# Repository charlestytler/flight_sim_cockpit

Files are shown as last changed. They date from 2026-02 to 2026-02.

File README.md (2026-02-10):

# Flight Sim Cockpit

Repository for Hardware and Embedded Software for flight simulation cockpit and avionics panels that provide input/output for Flight Simulators (DCS).

The cockpit is modeled on a blend of F/A-18C, A-10C, F-15E, and F-16C cockpits.

## Software 

The software directory contains embedded software that runs on Arduino and Raspberry Pi microcontrollers.
These connect to a PC via USB and emulate USB HID joystick devices and also communicate with DCS-BIOS software.

To-do: Develop a Windows PC middleware to connect USB Serial -> Middleware -> DCS-BIOS and avoid flashing DCS module-specific code to the microcontrollers.

## Hardware

(Partially) assembled cockpit.  

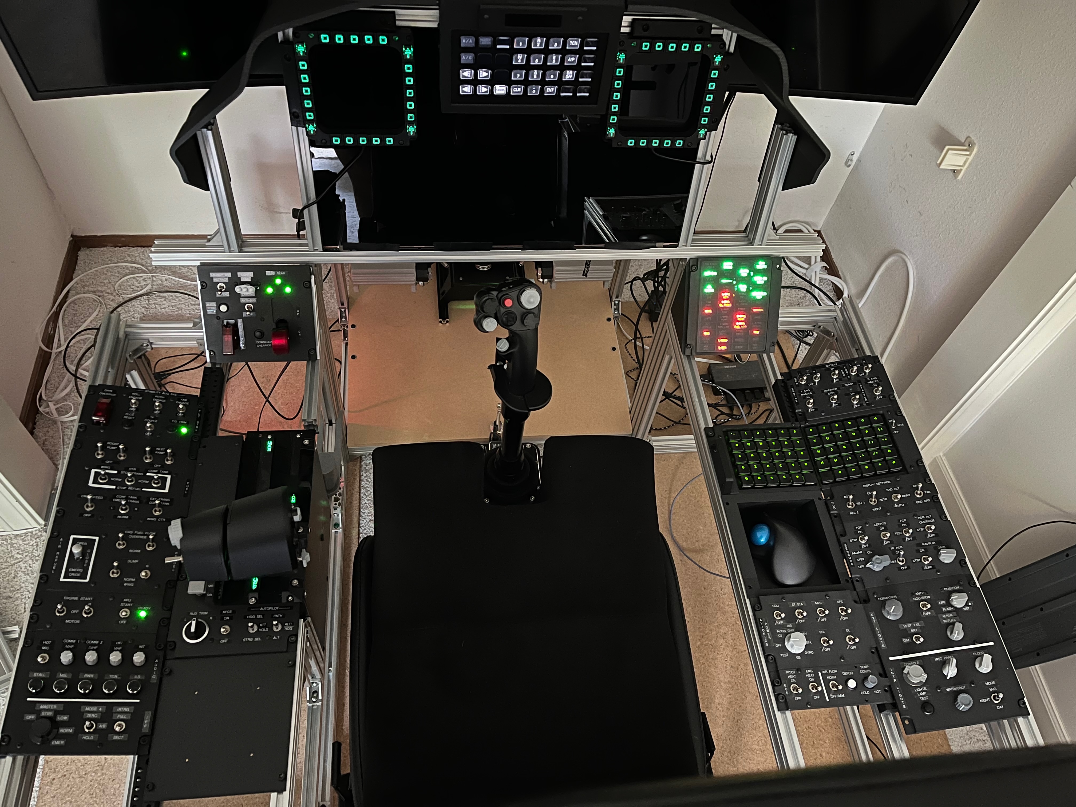
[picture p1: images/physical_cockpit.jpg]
Physical Cockpit


### CAD Models

#### [Link to Fusion 360 Web Viewer of CAD Model](https://a360.co/4bIpcXp)
- Frame is built out of 2040 and 2020 aluminum extrusion according to the CAD model.
- Chair frame uses same extrusion and also 3D Printed TPU surrounding bearings for sliding in/out.
- For complex angles (such as left/right console outer rails and corners), extrusion connectors are 3D printed.
- The panels themselves are a mix of 3D prints or acrylic machined with a CNC router.
- Temporary labels are added with a Brother label maker and 6mm white on black tape.
- Permanent labels are made by painting white acrylic panels matte black and laser engraving the text and symbols.
- Glare shield is designed in multiple parts to enable printing on a 256x256 3D printer bed.
  
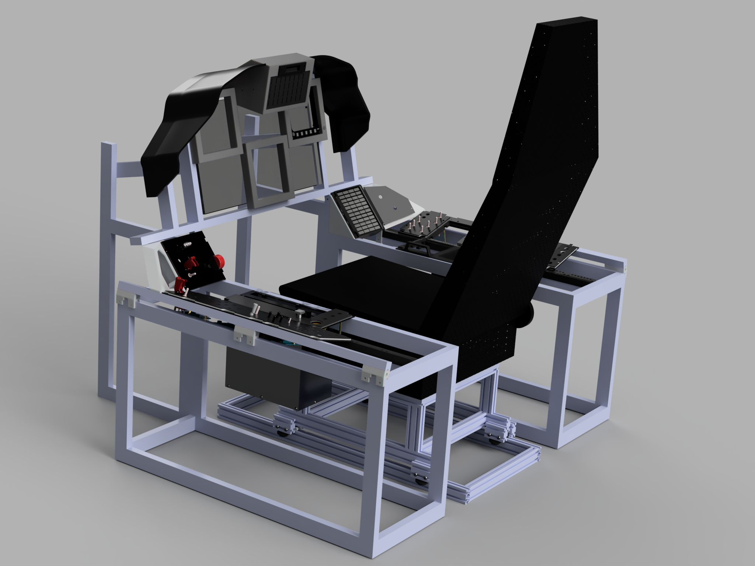
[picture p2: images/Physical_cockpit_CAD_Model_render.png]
CAD Model Rendering of Physical Cockpit


### PCBs

Current version of PCBs using:
 - Arduino Micro Pro (Atmel ATmega32U4)
    - Central processor for all I/O
    - Emulates a USB HID Joystick device
    - Communicates over Serial to PC middleware
    - Likely will upgrade to RP2040 Pico boards in next revision
 - PCF8575 I2C Expanders
    - Provides 16 digital I/O pins per board
    - Inputs used for Switches, Outputs used for indication LEDs
 - CD74HC4067 Multiplexers
    - Provides 16 to 1 analog input multiplexing
    - Used for reading analog potentiometers
 - RP2040 Raspberry Pi Pico (external of PCB)
    - Used for reading rotary encoders
    - Uses PIO to provide parallel handling of encoder interrupts
 - Screw Terminal breakouts

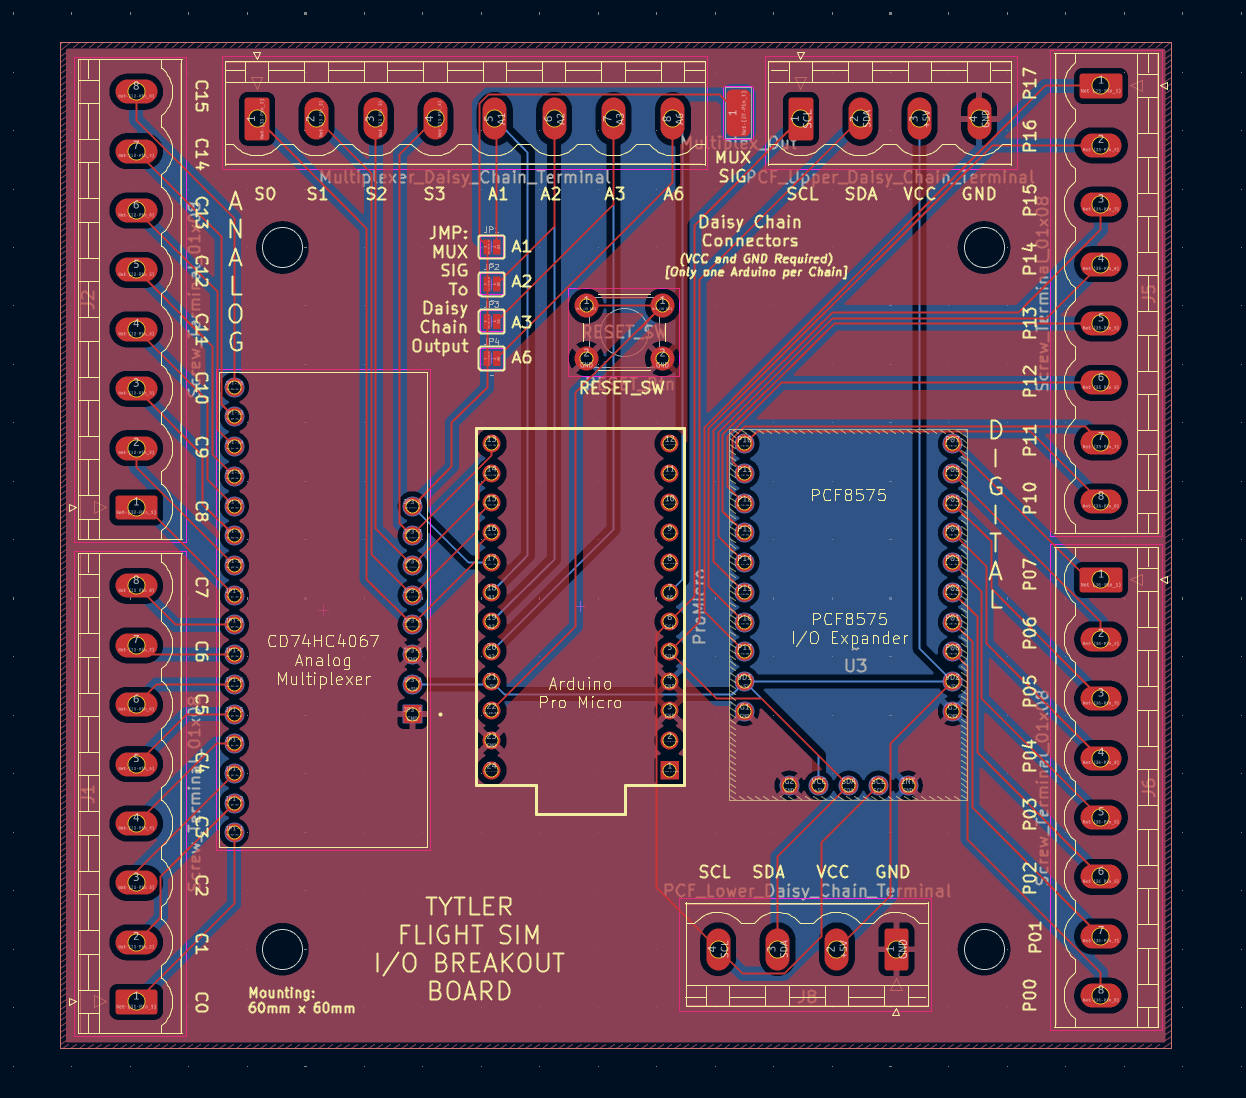
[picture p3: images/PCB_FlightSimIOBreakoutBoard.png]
PCB Layout

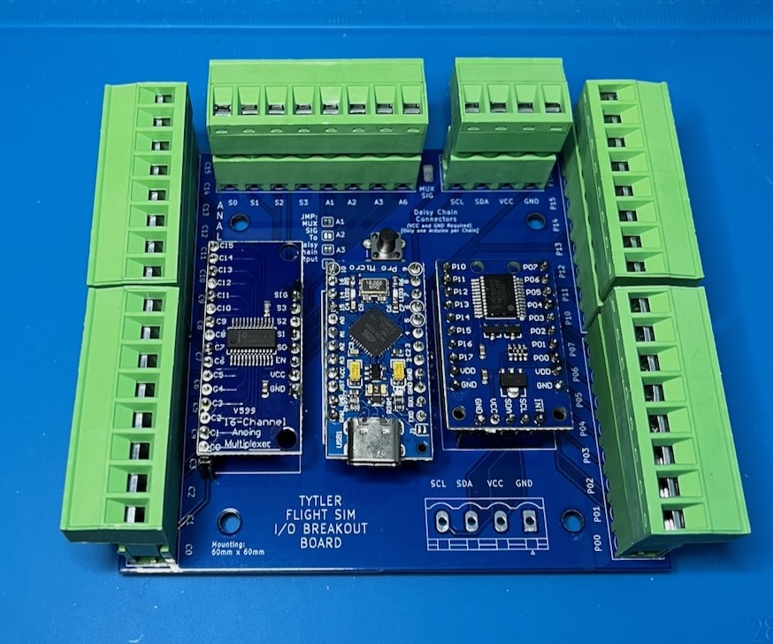
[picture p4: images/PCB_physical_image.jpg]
PCB with Soldered Components


### Cockpit Layout

The layout of avionics panels is a combination of functions from multiple aircraft, so some panels are replicas of specific aircraft, where others are a mix of multiple or have labels renamed to more generic functionality.

#### [Link to Cockpit Layout comparison to Real Aircraft layouts [Figma document]](https://www.figma.com/design/4pN5J7COTx5o1YJxnx6NWO/Layout-Diagram?node-id=0-1&t=OCtYUoI0DKsqzIj2-1)
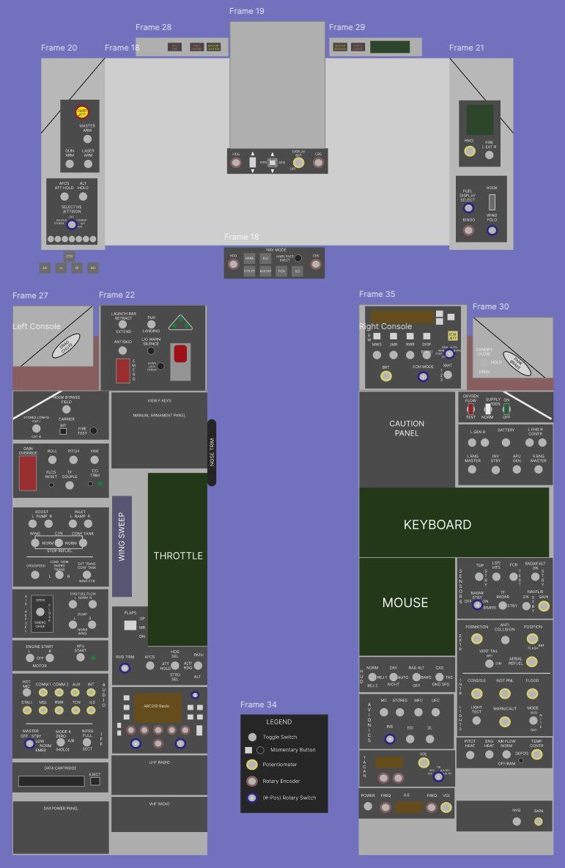
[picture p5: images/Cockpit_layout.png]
Cockpit Layout


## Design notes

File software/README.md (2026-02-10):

# Software

## Build Instructions

To compile: `make <board_name>`

To upload: `make upload <board_name>-upload PORT=COM<#>`
> *Note: if PORT is not specified a warning will print available ports*

To monitor Serial output: `make monitor PORT=COM<#>`

## Prerequisites
Must have arduino-cli installed: https://arduino.github.io/arduino-cli/latest/

Makefiles have been set up to use arduino-cli installed in Windows (arduino-cli.exe) but can be executed from WSL linux bash.

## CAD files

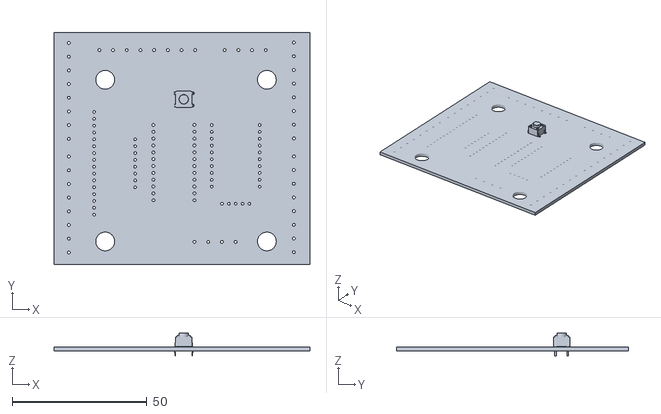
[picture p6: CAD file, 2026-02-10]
hardware/pcb/FlightSimIOBoard/FlightSimIOBoard.stl
95.0 x 86.0 x 8.50

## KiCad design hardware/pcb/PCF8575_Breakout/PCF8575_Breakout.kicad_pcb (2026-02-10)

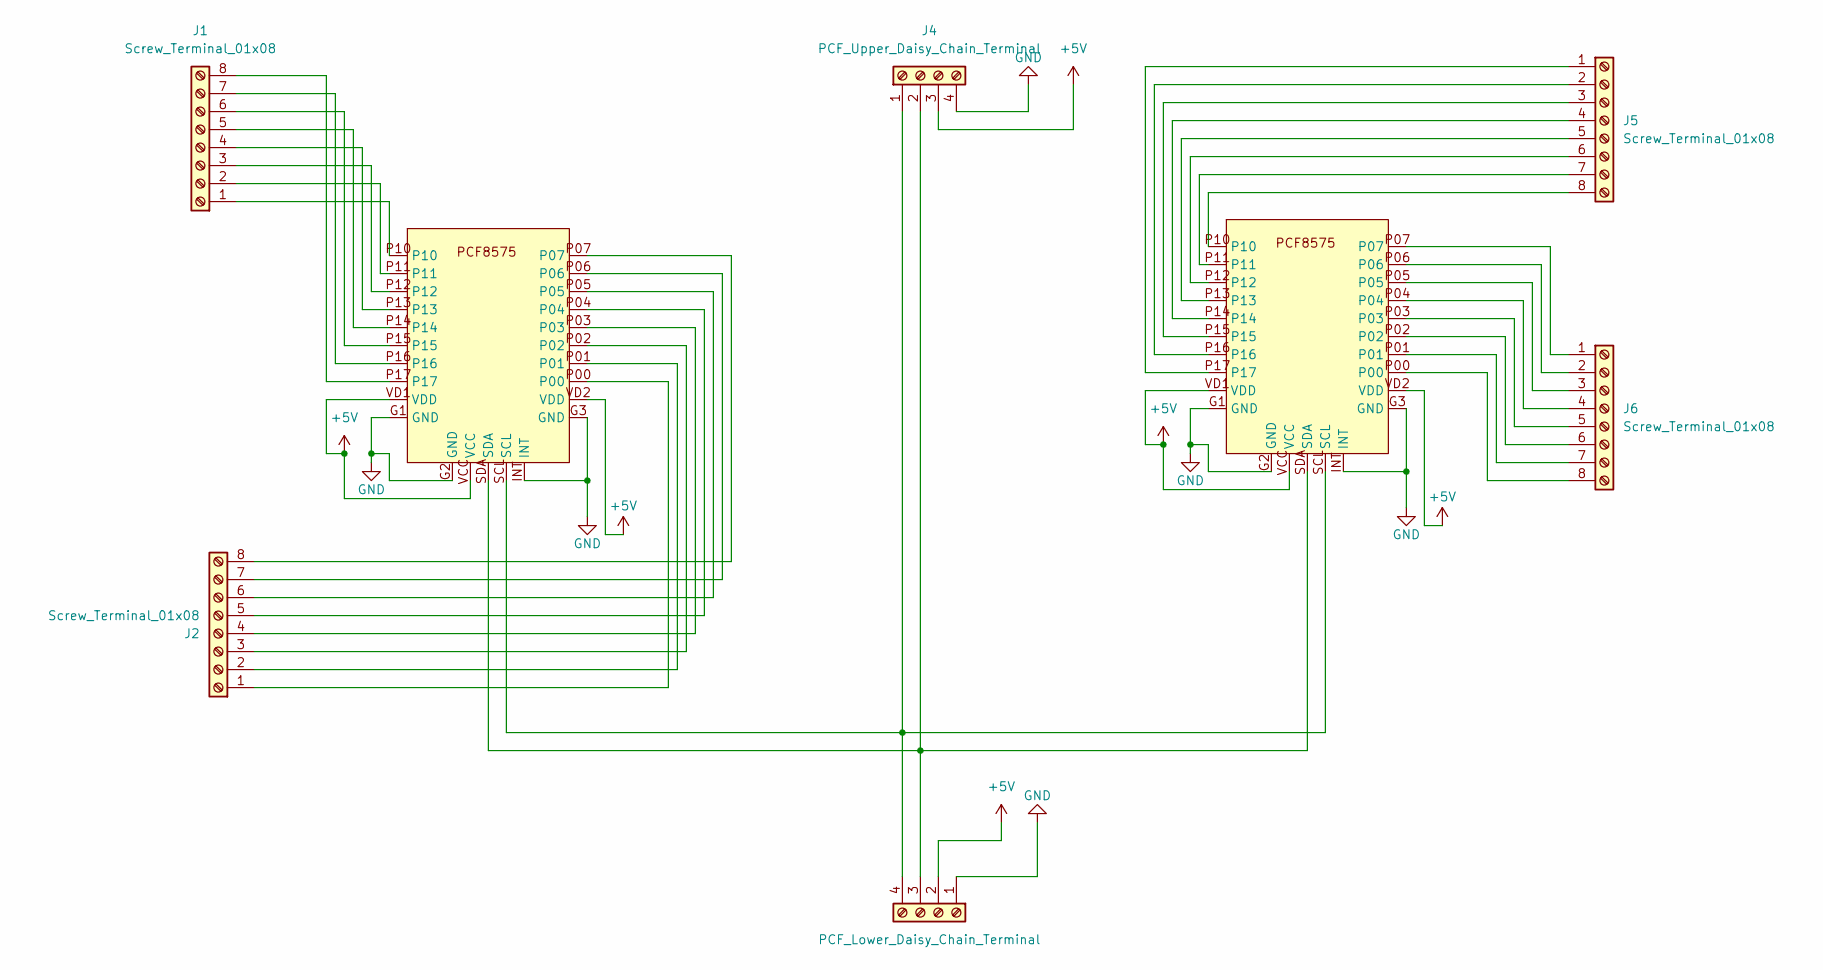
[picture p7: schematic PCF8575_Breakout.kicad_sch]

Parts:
J1, J2, J5, J6: Screw_Terminal_01x08; ScrewTerminal_2,5_8-G-5,08_1x08_P5.08mm_Vertical
J4: PCF_Upper_Daisy_Chain_Terminal; ScrewTerminal_2,5_4-G-5,08_1x04_P5.08mm_Vertical
J8: PCF_Lower_Daisy_Chain_Terminal; ScrewTerminal_2,5_4-G-5,08_1x04_P5.08mm_Vertical
U1, U3: PCF8575_Breakout

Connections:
+5V: J4.3, J8.2, U1.VCC, U1.VD1 (VDD), U1.VD2 (VDD), U3.VCC, U3.VD1 (VDD), U3.VD2 (VDD)
GND: J4.4, J8.1, U1.G1 (GND), U1.G2 (GND), U1.G3 (GND), U1.INT, U3.G1 (GND), U3.G2 (GND), U3.G3 (GND), U3.INT
unnamed: J1.1, U1.P10
unnamed: J1.2, U1.P11
unnamed: J1.3, U1.P12
unnamed: J1.4, U1.P13
unnamed: J1.5, U1.P14
unnamed: J1.6, U1.P15
unnamed: J1.7, U1.P16
unnamed: J1.8, U1.P17
unnamed: J2.1, U1.P00
unnamed: J2.2, U1.P01
unnamed: J2.3, U1.P02
unnamed: J2.4, U1.P03
unnamed: J2.5, U1.P04
unnamed: J2.6, U1.P05
unnamed: J2.7, U1.P06
unnamed: J2.8, U1.P07
unnamed: J4.1, J8.4, U1.SCL, U3.SCL
unnamed: J4.2, J8.3, U1.SDA, U3.SDA
unnamed: J5.1, U3.P17
unnamed: J5.2, U3.P16
unnamed: J5.3, U3.P15
unnamed: J5.4, U3.P14
unnamed: J5.5, U3.P13
unnamed: J5.6, U3.P12
unnamed: J5.7, U3.P11
unnamed: J5.8, U3.P10
unnamed: J6.1, U3.P07
unnamed: J6.2, U3.P06
unnamed: J6.3, U3.P05
unnamed: J6.4, U3.P04
unnamed: J6.5, U3.P03
unnamed: J6.6, U3.P02
unnamed: J6.7, U3.P01
unnamed: J6.8, U3.P00

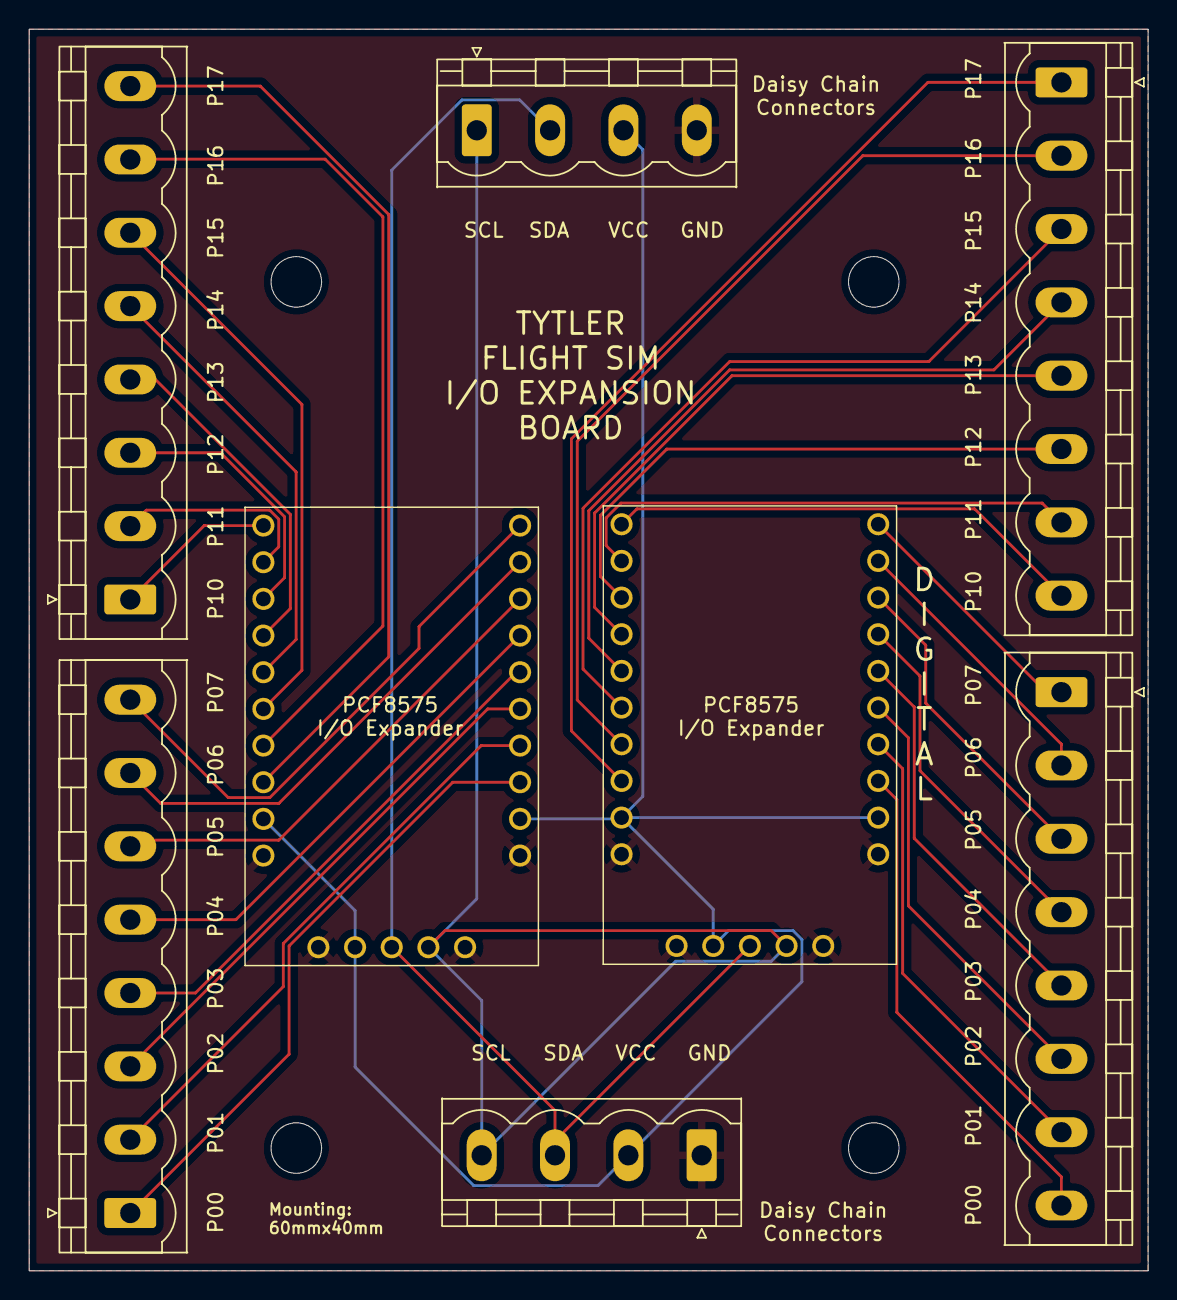
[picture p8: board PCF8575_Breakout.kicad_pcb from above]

Board: 2 copper layers, 77.5 x 86.0 mm, 8 parts (0 on the bottom side), 36 nets.

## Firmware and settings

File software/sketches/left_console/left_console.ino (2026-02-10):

#define DCSBIOS_DEFAULT_SERIAL

// #define DEBUG

#include "DcsBios.h"
#include "GpioExpander.h"
#include <Joystick.h>

const uint8_t hidReportId = 100;
const uint8_t buttonCount = 80;
const uint8_t hatSwitchCount = 0;
Joystick_ joystick(hidReportId,
                   JOYSTICK_TYPE_JOYSTICK,
                   buttonCount,
                   hatSwitchCount,
                   false, // include axes
                   false,
                   false,
                   false,
                   false,
                   false,
                   false,
                   false,
                   false,
                   false,
                   false);

// Arduino Pin Configuration

int btn_index = 0;

enum GpioExpanderNames {
    LDG_GEAR_1 = 0,
    LDG_GEAR_2,
    FLT_CONTROL,
    ENG_START,
    REFUEL,
    FUEL_1,
    FUEL_2,
    AFCS,
    NUM_GPIO_EXPANDERS // Maximum value of enum
};

GpioExpander io[NUM_GPIO_EXPANDERS];
GpioConfig io_configs[NUM_GPIO_EXPANDERS] = { //
    [LDG_GEAR_1] = {0b000, {L, L, L, L, X, X, X, X}, btn_index},
    [LDG_GEAR_2] = {0b100, {D, D, S, S, S, S, S, S}, btn_index += 8},
    [FLT_CONTROL] = {0b011, {L, S, S, S, S, S, S, S}, btn_index += 8},
    [ENG_START] = {0b010, {D, D, D, D, S, L, D, D}, btn_index += 8},
    [REFUEL] = {0b001, {D, D, S, S, S, S, S, X}, btn_index += 8},
    [FUEL_1] = {0b101, {S, S, S, S, D, D, D, D}, btn_index += 8},
    [FUEL_2] = {0b110, {D, D, S, D, D, S, X, X}, btn_index += 8},
    [AFCS] = {0b111, {D, D, D, D, S, D, D, X}, btn_index += 8}};

// Callback functions for specific LEDs.

void set_ldg_gear_handle_led(unsigned int value) { io[LDG_GEAR_1].set_led(0, value); }
void set_ldg_gear_left_led(unsigned int value) { io[LDG_GEAR_1].set_led(1, value); }
void set_ldg_gear_right_led(unsigned int value) { io[LDG_GEAR_1].set_led(2, value); }
void set_ldg_gear_nose_led(unsigned int value) { io[LDG_GEAR_1].set_led(3, value); }

void set_flt_control_to_trim_led(unsigned int value) { io[FLT_CONTROL].set_led(0, value); }
void set_eng_start_apu_led(unsigned int value) { io[ENG_START].set_led(7, value); }

void turn_off_all_leds()
{
    for (int i = 0; i < NUM_GPIO_EXPANDERS; i++) {
        io[i].set_all_led(0);
    }
}

// DCS BIOS Configuration

void onAcftNameChange(char *newValue) { turn_off_all_leds(); }
DcsBios::StringBuffer<24> AcftNameBuffer(0x0000, onAcftNameChange);

DcsBios::IntegerBuffer A10LdgGearHandle(0x1026, 0x4000, 14, set_ldg_gear_handle_led);
DcsBios::IntegerBuffer A10LdgGearLeft(0x1026, 0x1000, 12, set_ldg_gear_left_led);
DcsBios::IntegerBuffer A10LdgGearRight(0x1026, 0x2000, 13, set_ldg_gear_right_led);
DcsBios::IntegerBuffer A10LdgGearNose(0x1026, 0x0800, 11, set_ldg_gear_nose_led);

DcsBios::IntegerBuffer F18LdgGearHandle(0x747e, 0x0800, 11, set_ldg_gear_handle_led);
DcsBios::IntegerBuffer F18LdgGearLeft(0x7430, 0x1000, 12, set_ldg_gear_left_led);
DcsBios::IntegerBuffer F18LdgGearRight(0x7430, 0x2000, 13, set_ldg_gear_right_led);
DcsBios::IntegerBuffer F18LdgGearNose(0x7430, 0x0800, 11, set_ldg_gear_nose_led);
//
DcsBios::IntegerBuffer F18ApuReady(0x74c2, 0x0800, 11, set_eng_start_apu_led);

DcsBios::IntegerBuffer F16LdgGearHandle(0x447c, 0x0002, 1, set_ldg_gear_handle_led);
DcsBios::IntegerBuffer F16LdgGearLeft(0x447a, 0x8000, 15, set_ldg_gear_left_led);
DcsBios::IntegerBuffer F16LdgGearRight(0x447c, 0x0001, 0, set_ldg_gear_right_led);
DcsBios::IntegerBuffer F16LdgGearNose(0x447a, 0x4000, 14, set_ldg_gear_nose_led);

DcsBios::IntegerBuffer F15LgHndLBuffer(F_15E_F_LG_HND_L, set_ldg_gear_handle_led);
DcsBios::IntegerBuffer F15LgLeftGLBuffer(F_15E_F_LG_LEFT_G_L, set_ldg_gear_left_led);
DcsBios::IntegerBuffer F15LgRightGLBuffer(F_15E_F_LG_RIGHT_G_L, set_ldg_gear_right_led);
DcsBios::IntegerBuffer F15LgNoseGLBuffer(F_15E_F_LG_NOSE_G_L, set_ldg_gear_nose_led);
DcsBios::IntegerBuffer F15CasTrimLBuffer(F_15E_F_CAS_TRIM_L, set_flt_control_to_trim_led);
DcsBios::IntegerBuffer F15GenStarterLBuffer(F_15E_F_GEN_STARTER_L, set_eng_start_apu_led);

// Arduino Runtime

void setup()
{
#ifdef DEBUG
    Serial.begin(115200);
    delay(5000);
    Serial.println("START");
#endif

    DcsBios::setup();
    constexpr bool autoSendState = false;
    joystick.begin(autoSendState);

    Wire.begin();
    for (int i = 0; i < NUM_GPIO_EXPANDERS; i++) {
        io[i].setup(io_configs[i]);
    }
    turn_off_all_leds();
}

constexpr int LOOP_FRAME_TIME_MS = 10; // Run at 100Hz.
void loop()
{
    unsigned long frame_start_time_ms = millis();

    DcsBios::loop();

    for (int i = 0; i < NUM_GPIO_EXPANDERS; i++) {
        io[i].loop(joystick);
    }
#ifdef DEBUG
    Serial.println(" ");
#endif

    joystick.sendState();

    while (millis() - frame_start_time_ms < LOOP_FRAME_TIME_MS) {
        // Wait.
    }
}

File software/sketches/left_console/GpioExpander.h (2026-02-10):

#pragma once

#include <Joystick.h>
#include <PCF8574.h>

enum GpioType {
    S, // Single pole input
    D, // Double pole input
    M, // Multiple pole (e.g. rotary switch) input
    L, // LED output
    X  // Unused
};

typedef struct {
    uint8_t pcf_address; // Expected as binary of form 0b<A0><A1><A2>
    GpioType pins[8];
    int joystick_start_index;
} GpioConfig;

class GpioExpander
{
  public:
    GpioExpander() : gpio_board_() {}

    void set_configuration(GpioConfig &config)
    {
        uint8_t pcf_id = 0b100000 | config.pcf_address;
#ifdef DEBUG
        Serial.print("PCF ID: ");
        Serial.print(pcf_id, BIN);
        Serial.print("\t");
        Serial.println(pcf_id, HEX);
#endif
        gpio_board_.setAddress(pcf_id);

        /*
        Button mask for PCF8574 library:
        Bits set to 1 will set those pins HIGH then LOW to read button switch status.
        Bits set to 0 will be unaffected during the buttonRead8() call (good for LED outputs).
        */
        constexpr int NUM_PINS = 8;
        uint8_t button_mask = 0U;
        for (int i = 0; i < NUM_PINS; i++) {
            if (config.pins[i] == S || config.pins[i] == D || config.pins[i] == M) {
                bitWrite(button_mask, i, 1);
            }
        }
        gpio_board_.setButtonMask(button_mask);
#ifdef DEBUG
        Serial.print("Mask: ");
        Serial.println(button_mask, BIN);
#endif

        joystick_start_index_ = config.joystick_start_index;
    }

    void set_led(const uint8_t pin_id, const uint8_t value) { gpio_board_.write(pin_id, value); }

    void set_all_led(const uint8_t value) { gpio_board_.write8(value); }

    void setup(GpioConfig &config)
    {
        set_configuration(config);
        gpio_board_.begin();
    }

    void loop(Joystick_ &joystick)
    {
        uint8_t pin_values = gpio_board_.readButton8();
#ifdef DEBUG
        Serial.print("B");
        Serial.print(gpio_board_.getAddress(), BIN);
        Serial.print(": ");
        Serial.print(pin_values, BIN);
        Serial.print(" ");
#endif

        for (int i = 0; i < 8; i++) {
            if (bitRead(gpio_board_.getButtonMask(), i)) {
                joystick.setButton(joystick_start_index_ + i, !(bitRead(pin_values, i)));
            }
        }
    }

  private:
    PCF8574 gpio_board_;
    int joystick_start_index_;
};

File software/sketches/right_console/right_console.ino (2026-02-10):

#include <FlightSimBreakoutBoard.h>

constexpr FlightSimBreakoutBoardConfig config{
    .digital_io_expanders_config =
        {
            .expander_i2c_addresses = {0x20, 0x21, 0x22},
            .num_expanders = 3, // num_expanders
            .num_leds = 0,      // num_leds
        },
    .analog_multiplexer_config = {
        .pins = {.s0 = 15, .s1 = 14, .s2 = 16, .s3 = 10}, // Channel Select pins
        .num_mux_inputs = 1,
        .mux_input_pins = {A0},
    }};

// const FlightSimBreakoutBoardConfig config{
//     {
//         // digital_io_expanders_config
//         {0x20},
//         1, // num_expanders
//         0, // num_leds
//     },
//     {
//         // analog_multiplexer_config
//         {A0, A1, A2, A3}, // Channel Select pins
//         4,                // num_mux_inputs
//     }};

FlightSimBreakoutBoard flightSimBreakoutBoard(config);

void setup() {
  Serial.begin(115200);
  while (!Serial) {
  }

  flightSimBreakoutBoard.setup(config);
}

void loop() { flightSimBreakoutBoard.loop(config); }

//
//
// Checks on configuration.

static_assert(config.digital_io_expanders_config.num_leds <=
                  NUM_PINS_PER_IO_EXPANDER *
                      config.digital_io_expanders_config.num_expanders,
              "More LEDs than available pins.");

static_assert(config.digital_io_expanders_config.num_expanders <=
                  MAX_NUM_DIGITAL_IO_EXPANDERS,
              "More expanders than number of I2C addresses available.");

static_assert(config.analog_multiplexer_config.num_mux_inputs <=
                  MAX_NUM_MULTIPLEXERS,
              "More mux inputs than max configuration supports.");

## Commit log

2026-02-10 Update readme with PCB images
2026-02-10 Upload KiCAD PCB files
    [FlightSimIOBoard-B_Cu.gbr, FlightSimIOBoard-B_Mask.gbr, FlightSimIOBoard-B_Paste.gbr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]
2026-02-10 Add CAD model image and link
